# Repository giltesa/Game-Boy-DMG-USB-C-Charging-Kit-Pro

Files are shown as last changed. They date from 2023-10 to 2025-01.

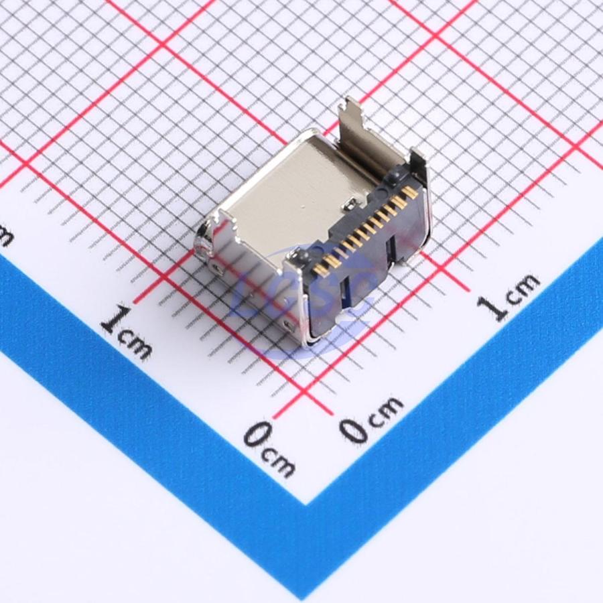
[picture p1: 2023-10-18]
3. Documentation/Datasheet/USB-C/20230608_Hanbo-Electronic-MC-108-DG30_C6332273_back.jpg

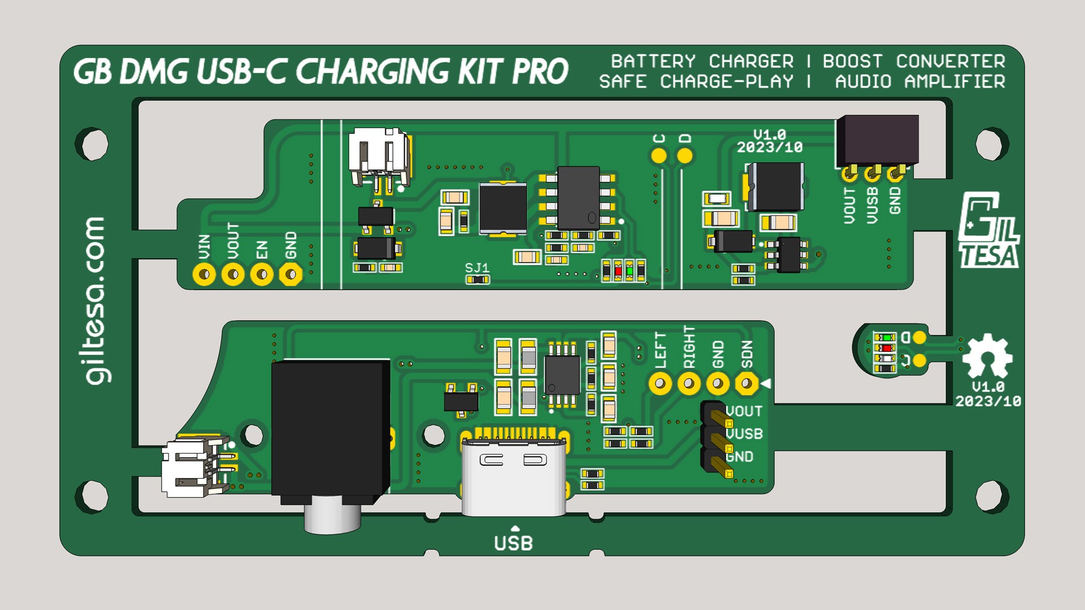
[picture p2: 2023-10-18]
2. Renders, 3D models/GB DMG PRO - v1.0.jpg

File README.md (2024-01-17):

# Game Boy DMG: USB-C Charging Kit PRO

The **Game Boy DMG USB-C Charging Kit PRO** is a new circuit designed specifically for the **Nintendo Game Boy**. This all-in-one circuit includes not only the **charging controller** but also a **boost converter** and **audio amplifier**.

The modern **IPS displays** with backlighting require more power than the original display, and **flash cards** used to load tons of games can quickly drain the battery. To truly enjoy the games, it is recommended to use a rechargeable battery instead of AA batteries.

However, simply using a rechargeable battery is not sufficient. The increased power consumption puts a strain on the original electronics, potentially causing noise in the speaker or headphones.

The typical solution is to add a charging circuit for the battery and a power converter to replace the old, inefficient one included in the GB. Some individuals also add an audio amplifier to enhance the sound quality of the speaker. All these modifications make the GBP function optimally. However, installing them requires numerous cables and may be challenging for individuals without sufficient knowledge.

This board adds all these features with a clean and straightforward installation:

(https://shop.giltesa.com/wp-content/uploads/2023/08/GB-DMG-PRO-v1.2_panel.jpg)

## Would you like it?

https://shop.giltesa.com/product/game-boy-dmg-usb-c-charging-kit/

## More

- [giltesa.com](https://giltesa.com "giltesa.com")
- [twitter.com](https://twitter.com/giltesa "twitter.com")

## License

This project is licensed under a **Creative Commons** license:
**[Attribution-NonCommercial-ShareAlike 4.0 International (CC BY-NC-SA 4.0) ](https://creativecommons.org/licenses/by-nc-sa/4.0/)**

Check the [LICENSE.md](LICENSE.md) for more information.

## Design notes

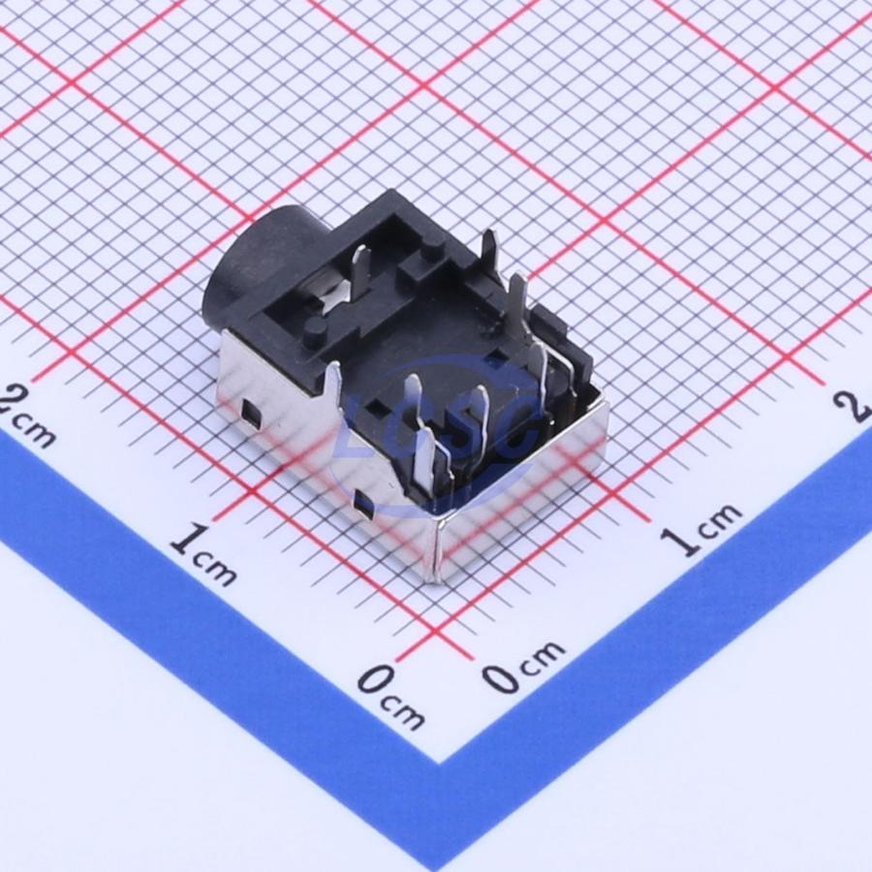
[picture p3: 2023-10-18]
3. Documentation/Datasheet/Headphone jack/20230105_XKB-Connectivity-PJ-3043-B_C2682182_back.jpg

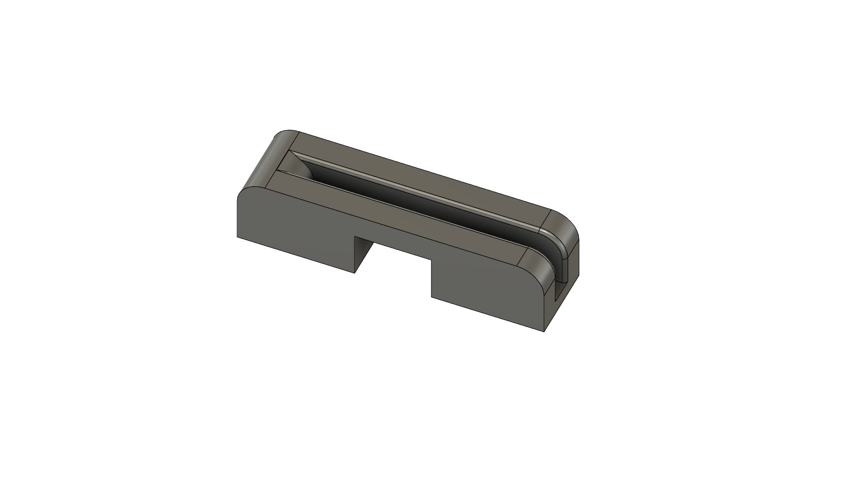
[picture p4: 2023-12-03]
2. Renders, 3D models/Cutting Tool/GB DMG - Cutting Tool v13.png

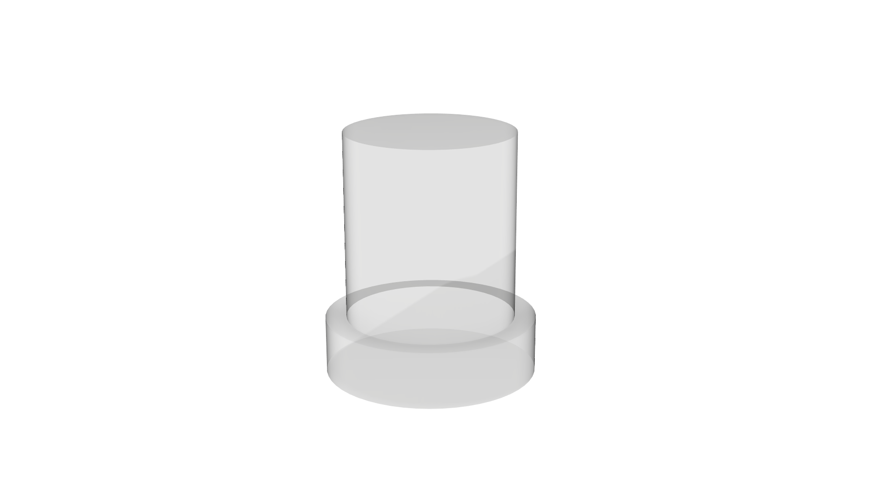
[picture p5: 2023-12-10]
2. Renders, 3D models/Light diffuser pipe/GB DMG - Light diffuser pipe v5.png

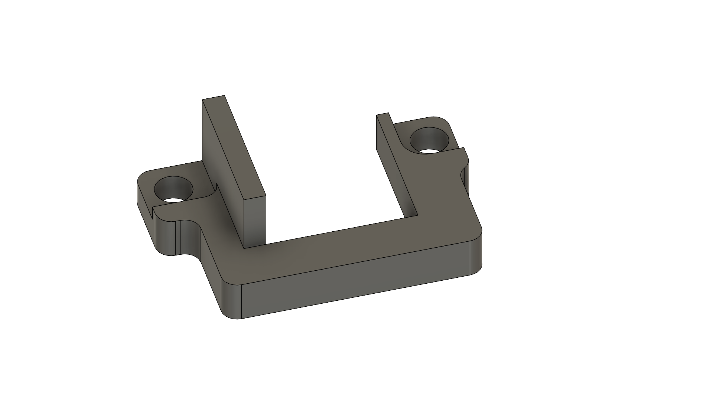
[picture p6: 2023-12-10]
2. Renders, 3D models/Jack Spacer/GB DMG - Jack Spacer v15.png

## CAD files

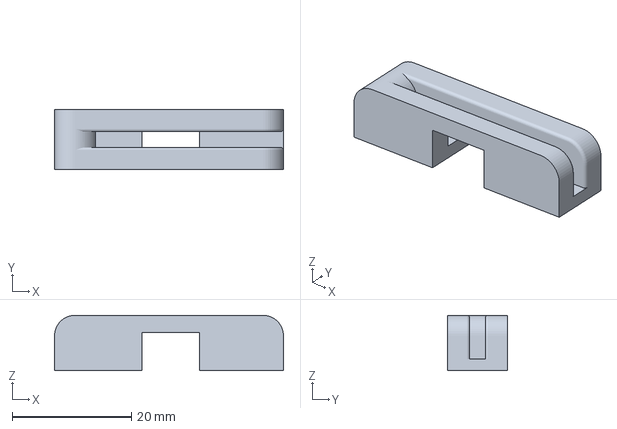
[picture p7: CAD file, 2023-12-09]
2. Renders, 3D models/Cutting Tool/GB DMG - Cutting Tool v13.3mf
38.4 x 10.0 x 9.30 mm

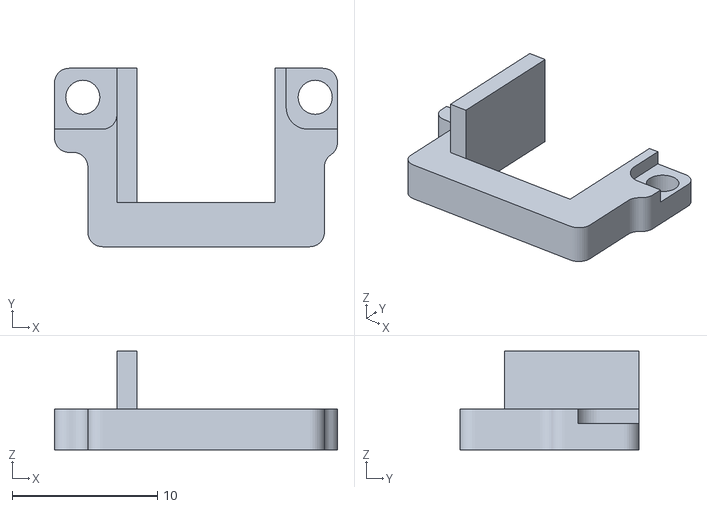
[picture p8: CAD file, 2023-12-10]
2. Renders, 3D models/Jack Spacer/GB DMG - Jack Spacer v15.stl
19.5 x 12.3 x 6.80

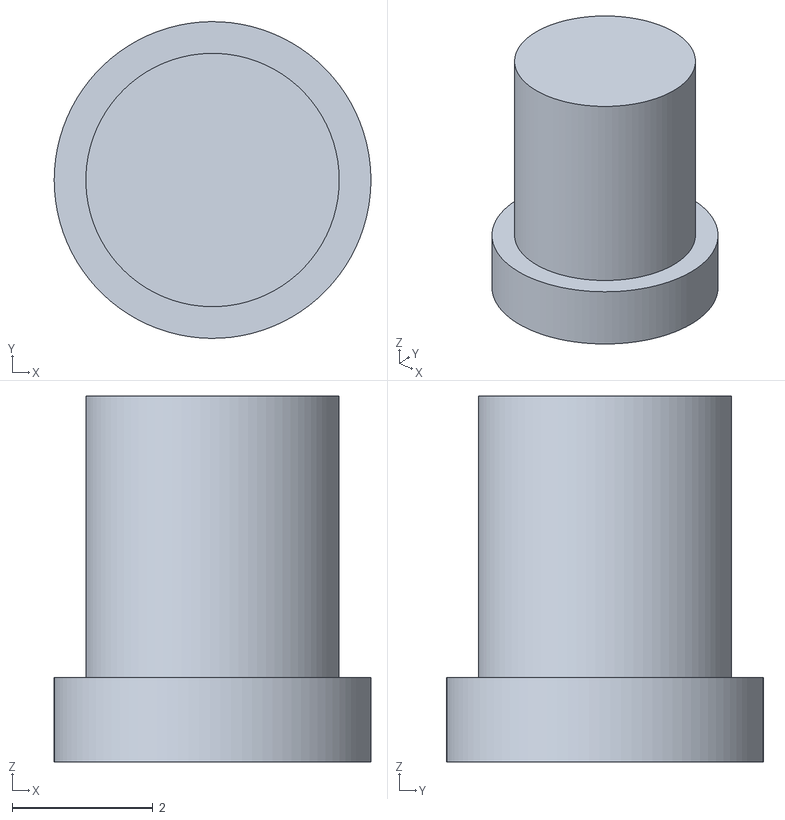
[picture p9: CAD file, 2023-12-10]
2. Renders, 3D models/Light diffuser pipe/GB DMG - Light diffuser pipe v5.stl
4.50 x 4.50 x 5.20

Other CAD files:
2. Renders, 3D models/Cutting Tool/GB DMG - Cutting Tool v13.f3d
2. Renders, 3D models/Cutting Tool/GB DMG - Cutting Tool v13.stl
2. Renders, 3D models/GB DMG - v1.0 - Frame.skp
2. Renders, 3D models/GB DMG - v1.1 - Frame.skp
2. Renders, 3D models/GB DMG - v1.2 - Frame.skp
2. Renders, 3D models/Jack Spacer/GB DMG - Jack Spacer v15.f3d
2. Renders, 3D models/Light diffuser pipe/GB DMG - Light diffuser pipe v5.f3d

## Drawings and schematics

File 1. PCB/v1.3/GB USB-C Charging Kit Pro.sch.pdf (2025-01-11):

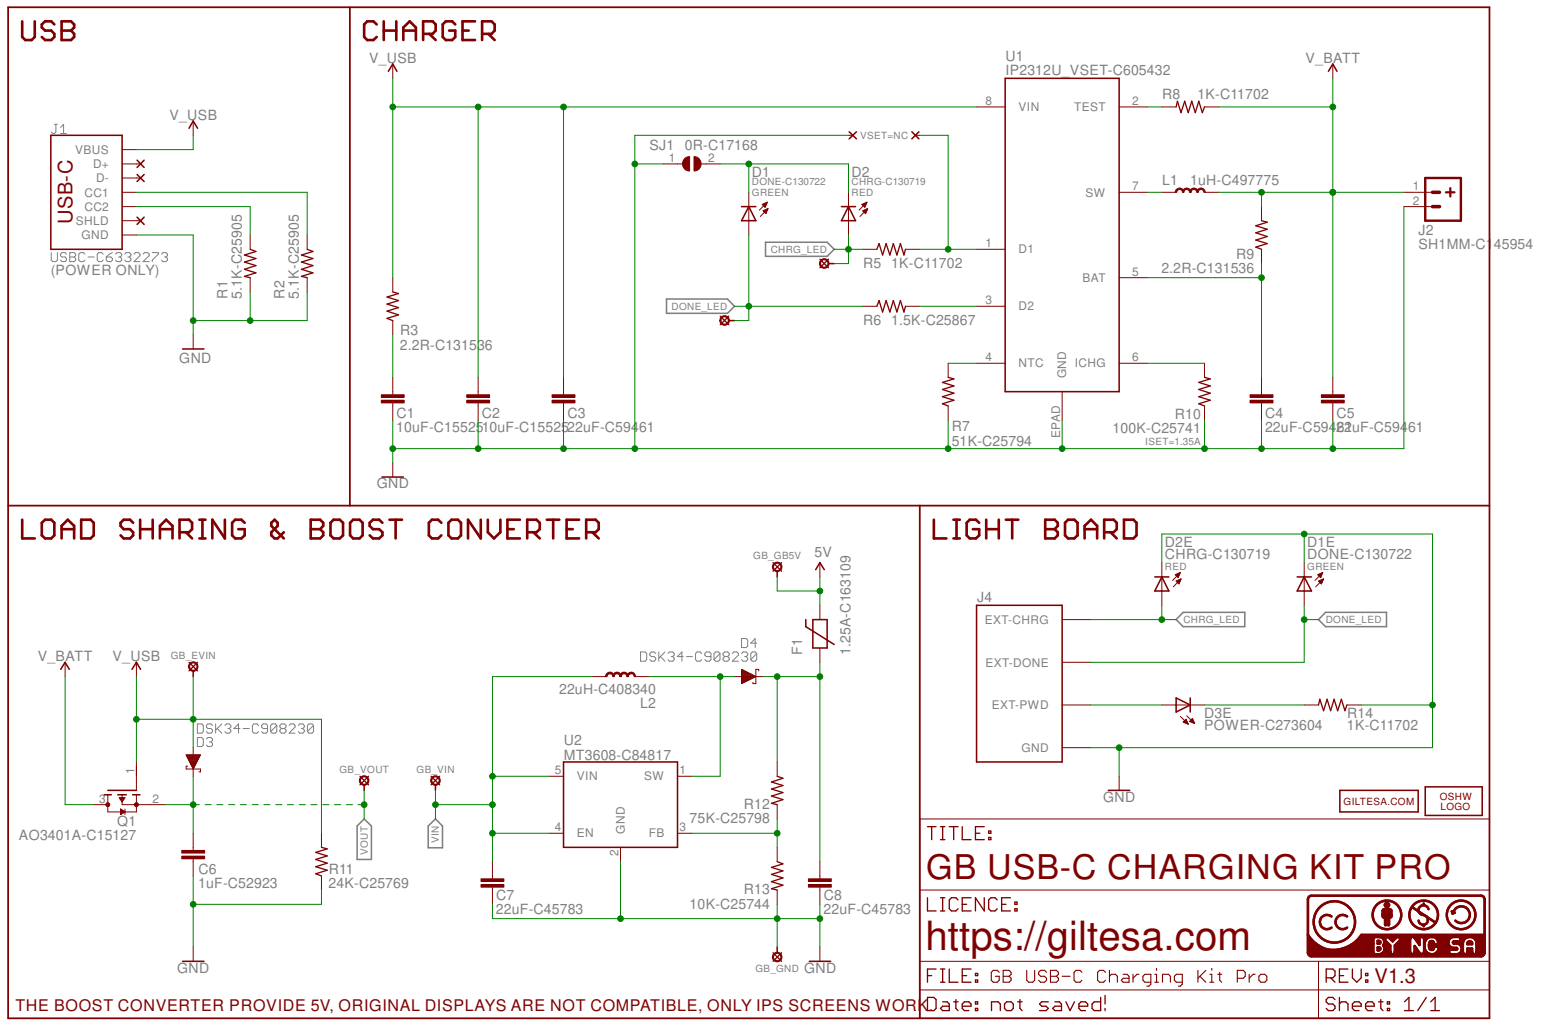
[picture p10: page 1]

D1 1 D2 3 NTC 4 | 1uH-C497775

GB USB-C CHARGING KIT PRO
https://giltesa.com

THE BOOST CONVERTER PROVIDE 5V, ORIGINAL DISPLAYS ARE NOT COMPATIBLE, ONLY IPS SCREENS WORK.

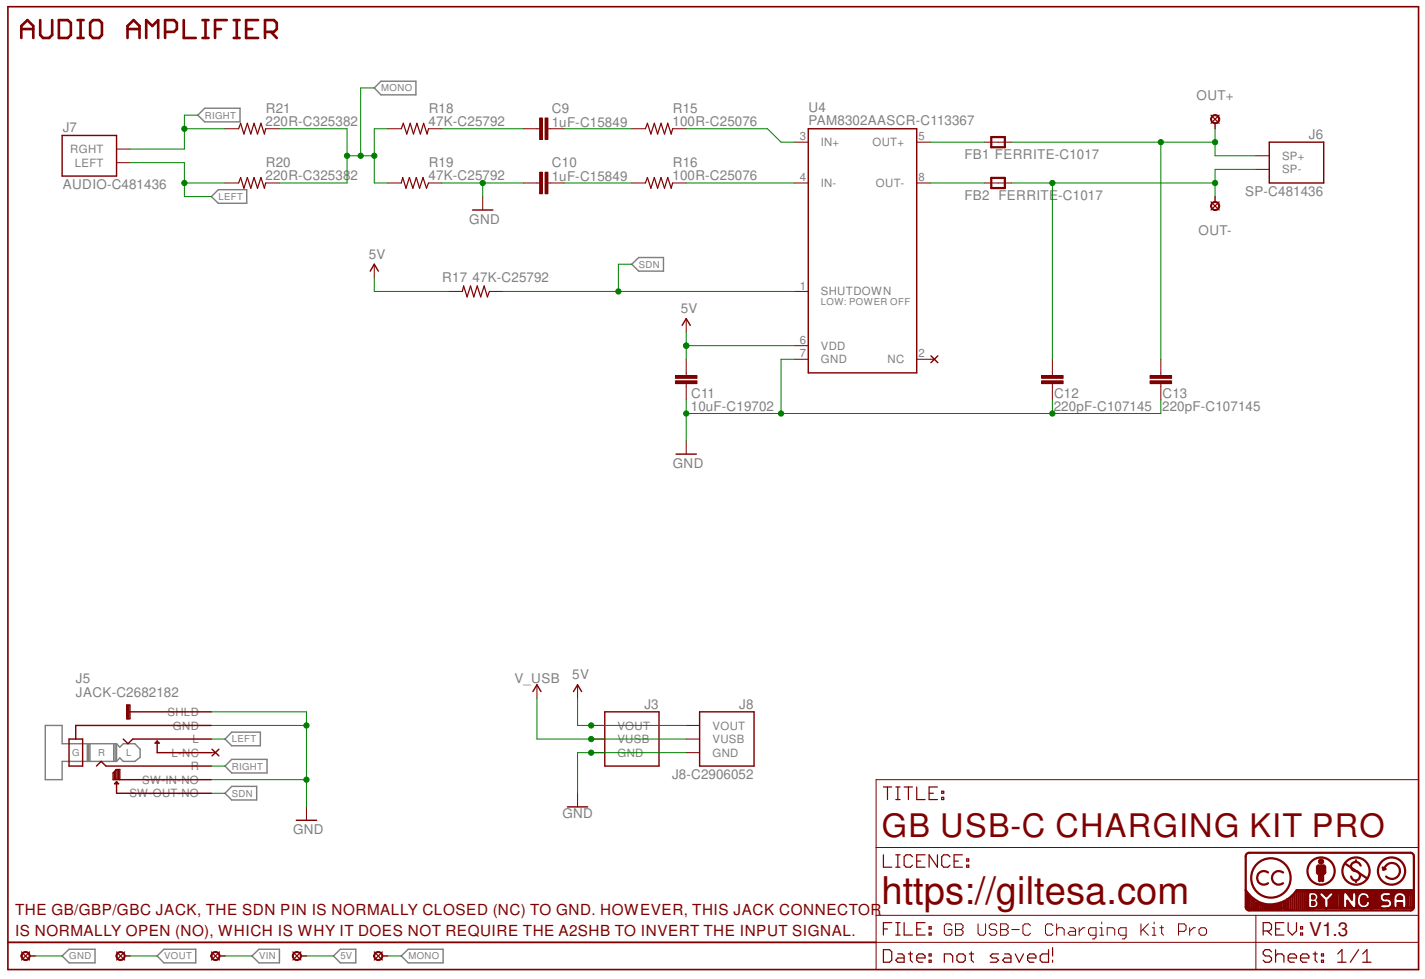
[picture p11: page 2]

GB USB-C CHARGING KIT PRO
https://giltesa.com

THE GB/GBP/GBC JACK, THE SDN PIN IS NORMALLY CLOSED (NC) TO GND. HOWEVER, THIS JACK CONNECTOR
IS NORMALLY OPEN (NO), WHICH IS WHY IT DOES NOT REQUIRE THE A2SHB TO INVERT THE INPUT SIGNAL.

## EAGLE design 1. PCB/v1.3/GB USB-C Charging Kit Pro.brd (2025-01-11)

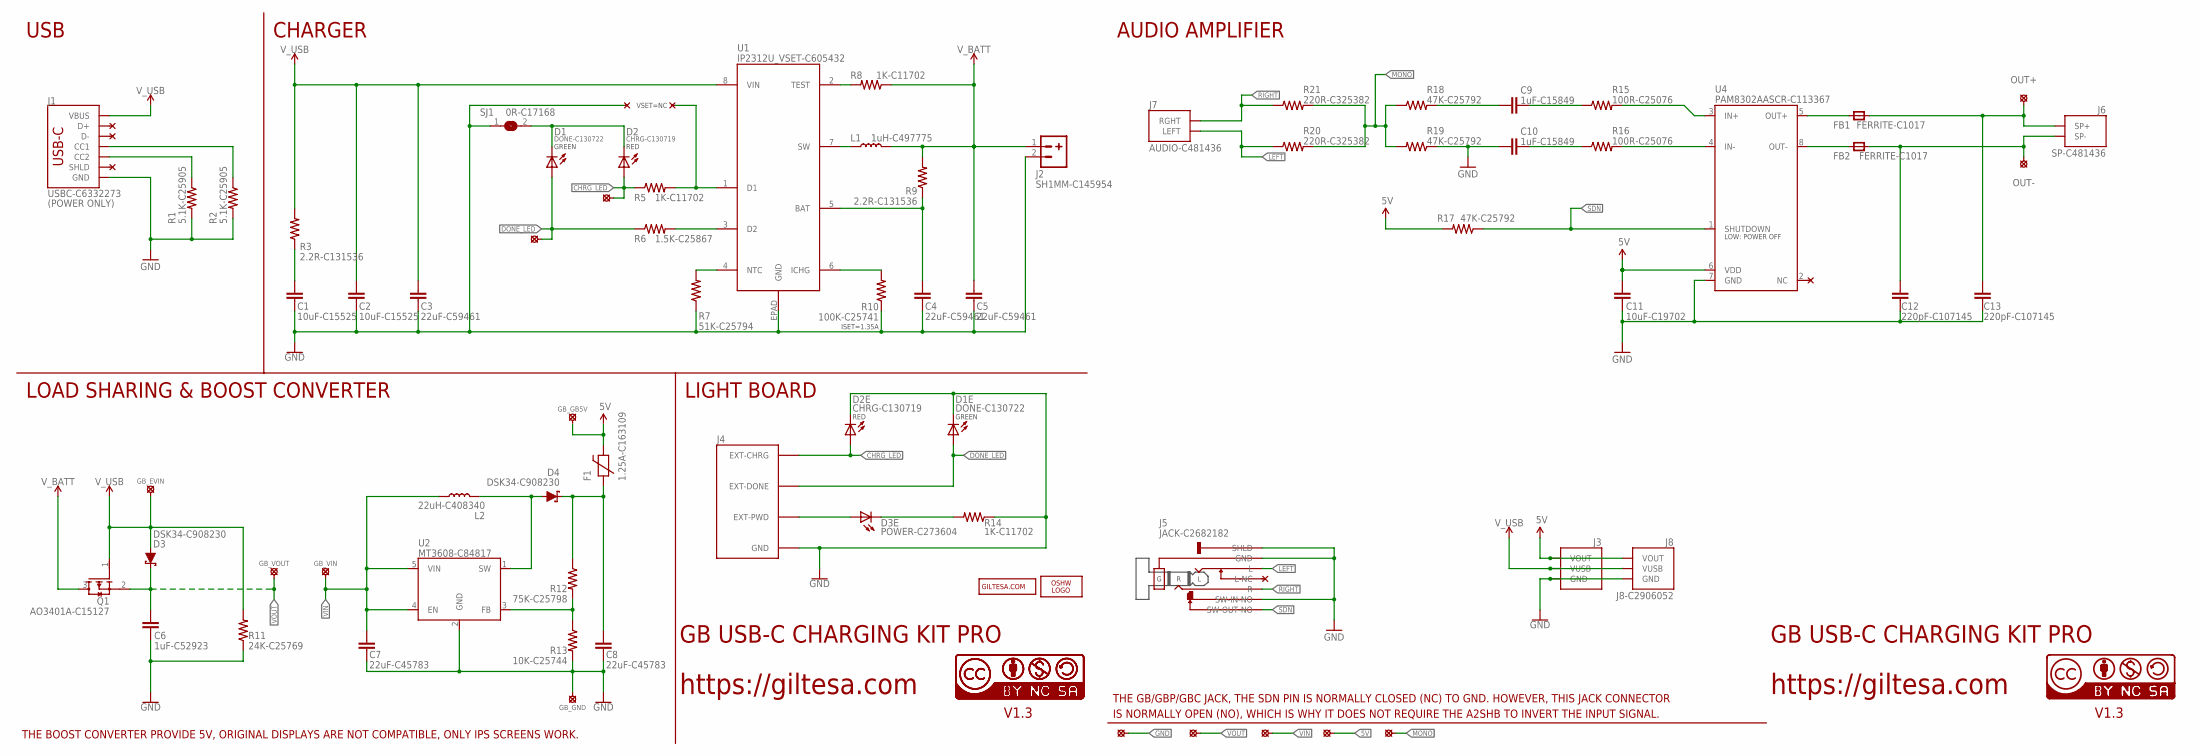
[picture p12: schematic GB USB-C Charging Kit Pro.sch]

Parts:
C1, C2: 10uF-C15525; C0402_S
C3, C4, C5: 22uF-C59461; C0603_S
C6: 1uF-C52923; C0402_S
C7, C8: 22uF-C45783; C0805_S
C9, C10: 1uF-C15849; C0603_S
C11: 10uF-C19702; C0603_S
C12, C13: 220pF-C107145; C0805_S
D1, D1E: DONE-C130722; L0402
D2, D2E: CHRG-C130719; L0402
D3, D4: DSK34-C908230; SOD-123FL
D3E: POWER-C273604; L0402
F1: 1.25A-C163109; F0603_S
FB1, FB2: FERRITE-C1017; MICROBUILDER__0805MP_S
GBL_: LED-C481436; GB_DMG_JST_LED
GB_: POWER-C2845538; GB_DMG_JST_POWER
J1: USBC-C6332273; USB-C_16P_3MM
J2: SH1MM-C145954; JST-2-1MM-SMD_RIGHT
J3: GB_DMG_BRIDGE_2.0MM_UP
J4: GB_DMG_LED
J5: JACK-C2682182; GB_DMG_JACK
J6: SP-C481436; GB_DMG_JST_SPEAKER
J7: AUDIO-C481436; GB_DMG_JST_AUDIO
J8: J8-C2906052; GB_DMG_BRIDGE_2.0MM_RIGHT
L1: 1uH-C497775; PSPMAA0402
L2: 22uH-C408340; PSPMAA0402
LOGO2: OSHW_LOGO_FILLX0150-NT; OSHW_FILLX150_NOTEXT
PP1, PP2, PP3, PP4, PP6: SOLDER_PAD-1.3; SOLDER_PAD_1.3
Q1: AO3401A-C15127; SOT23-3_S
R1, R2: 5.1K-C25905; R0402
R3, R9: 2.2R-C131536; R0402
R5, R8, R14: 1K-C11702; R0402
R6: 1.5K-C25867; R0402
R7: 51K-C25794; R0402
R10: 100K-C25741; R0402
R11: 24K-C25769; R0402
R12: 75K-C25798; R0402
R13: 10K-C25744; R0402
R15, R16: 100R-C25076; R0402
R17, R18, R19: 47K-C25792; R0402
R20, R21: 220R-C325382; R0402
SJ1: 0R-C17168; JUMPER-SMD_0402
U1: IP2312U_VSET-C605432; IP2312
U2: MT3608-C84817; SOT-23-6
U4: PAM8302AASCR-C113367; PAM8302AASCR
U$6: CC-BY-NC-SA15MM; CC-BY-NC-SA_15MM
U$16: GILTESA.COM_MASK; GILTESA.COM_MASK_15MM
U$17, U$21: CC-NC-BCNIX; CC-NC-B_NIX
U$20: OUT+; SOLDER_PAD_1.3
U$23: OUT-; SOLDER_PAD_1.3

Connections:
5V: C11.1, F1.2, GB_.GB5V, J3.VOUT, J8.VOUT, PP1.P$1, R17.2, U4.6 (VDD)
CHRG_LED: D2.A, D2E.A, GBL_.CHRG, J4.EXT-CHRG, R5.1
DONE_LED: D1.A, D1E.A, GBL_.DONE, J4.EXT-DONE, R6.1
GND: C1.1, C2.1, C3.1, C4.1, C5.1, C6.2, C7.1, C8.1, C10.2, C11.2, C12.2, C13.2, D1E.C, D2E.C, GB_.GND, J1.GND1 (GND), J1.GND2 (GND), J2.2, J3.GND, J4.PWD-GND (GND), J4.PWD-GND' (GND), J5.1 (GND), J5.1" (GND), J5.5 (SW-IN-NO), J5.8 (SHLD), J5.8' (SHLD), J8.GND, PP2.P$1, R1.2, R2.2, R7.1, R10.1, R11.1, R13.2, R14.1, R19.1, SJ1.1, U1.EPAD (GND), U2.2 (GND), U4.7 (GND)
LEFT: J5.3 (L), J7.LEFT, R20.1
MONO: PP6.P$1, R18.1, R19.2, R20.2, R21.2
unnamed: D1.C, D2.C, SJ1.2
unnamed: C8.2, D4.C, F1.1, R12.1
unnamed: D4.A, L2.P$2 (2), U2.1 (SW)
unnamed: J1.B5-CC2 (CC2), R1.1
unnamed: R8.2, U1.2 (TEST)
unnamed: R12.2, R13.1, U2.3 (FB)
unnamed: R16.2, U4.4 (IN-)
unnamed: D3E.A, J4.EXT-PWD
unnamed: D3E.C, R14.2
unnamed: R15.2, U4.3 (IN+)
unnamed: J1.A5-CC1 (CC1), R2.1
unnamed: C4.2, R9.1, U1.5 (BAT)
unnamed: C1.2, R3.1
unnamed: C10.1, R16.1
unnamed: FB2.1, U4.8 (OUT-)
unnamed: R5.2, U1.1 (D1)
unnamed: FB1.1, U4.5 (OUT+)
unnamed: C9.1, R15.1
unnamed: C9.2, R18.2
unnamed: R7.2, U1.4 (NTC)
unnamed: R10.2, U1.6 (ICHG)
unnamed: R6.2, U1.3 (D2)
unnamed: L1.P$1 (1), U1.7 (SW)
OUT+: C13.1, FB1.2, J6.SP+, U$20.P$1
OUT-: C12.1, FB2.2, J6.SP-, U$23.P$1
RIGHT: J5.2 (R), J7.RGHT, R21.1
SDN: J5.6 (SW-OUT-NO), R17.1, U4.1 (SHUTDOWN)
VIN: C7.2, GB_.VIN, L2.P$1 (1), PP3.P$1, U2.4 (EN), U2.5 (VIN)
VOUT: C6.1, D3.C, GB_.VOUT, PP4.P$1, Q1.2 (S)
V_BATT: C5.2, J2.1, L1.P$2 (2), Q1.3 (D), R8.1, R9.2
V_USB: C2.2, C3.2, D3.A, GB_.EVIN, J1.VBUS1 (VBUS), J1.VBUS2 (VBUS), J3.VUSB, J8.VUSB, Q1.1 (G), R3.2, R11.2, U1.8 (VIN)

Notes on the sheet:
GB USB-C CHARGING KIT PRO
https://giltesa.com
V1.3
(POWER ONLY)
THE BOOST CONVERTER PROVIDE 5V, ORIGINAL DISPLAYS ARE NOT COMPATIBLE, ONLY IPS SCREENS WORK.
USB
CHARGER
LOAD SHARING & BOOST CONVERTER
AUDIO AMPLIFIER
LIGHT BOARD
ISET=1.35A
GREEN
RED
VSET=NC
THE GB/GBP/GBC JACK, THE SDN PIN IS NORMALLY CLOSED (NC) TO GND. HOWEVER, THIS JACK CONNECTOR
IS NORMALLY OPEN (NO), WHICH IS WHY IT DOES NOT REQUIRE THE A2SHB TO INVERT THE INPUT SIGNAL.

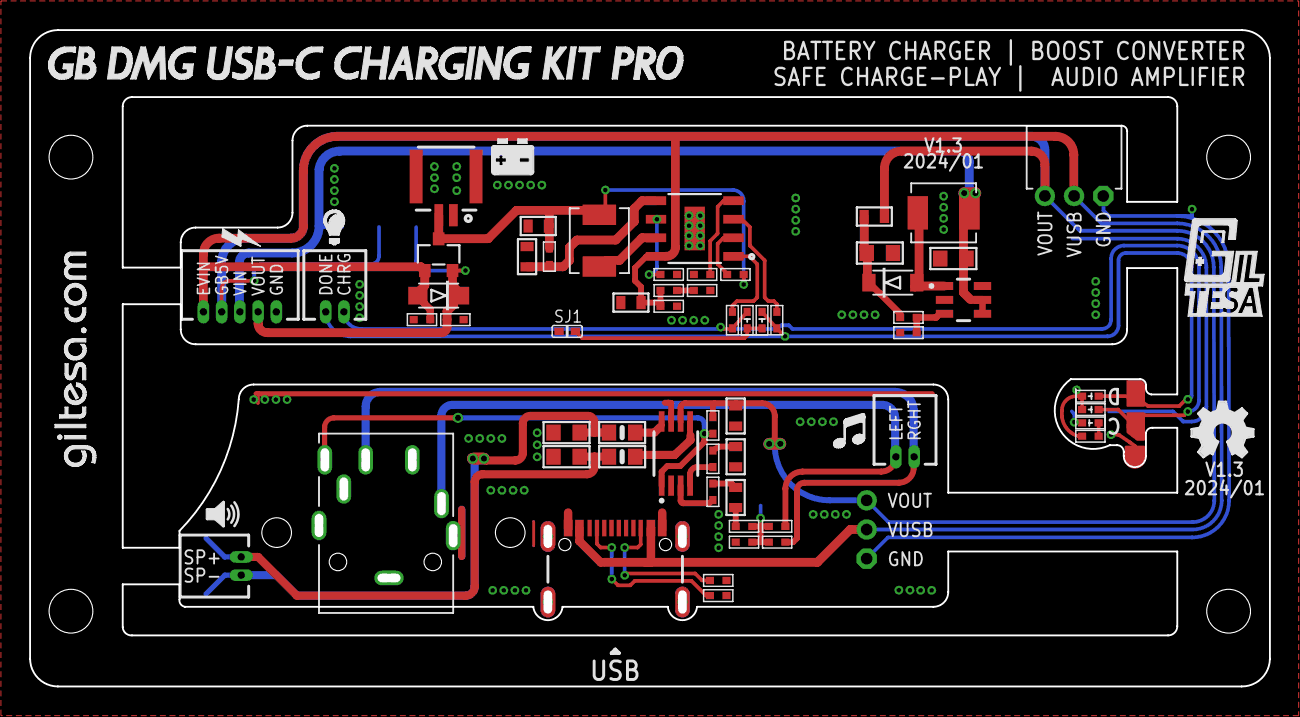
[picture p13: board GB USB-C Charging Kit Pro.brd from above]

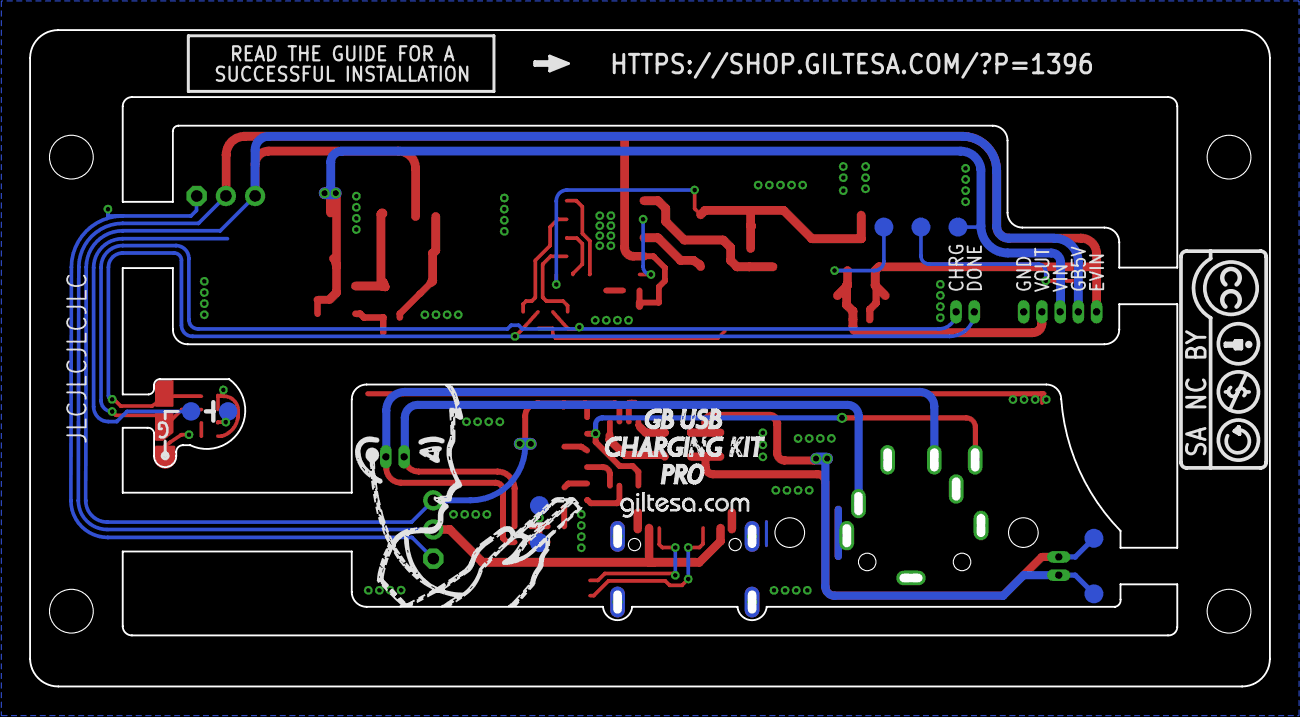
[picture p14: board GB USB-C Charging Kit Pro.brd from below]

Board: 2 copper layers, 85.0 x 45.0 mm, 82 parts (11 on the bottom side), 37 nets.

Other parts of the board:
U$1: SPEAKER
U$4: BATTERY
U$7: GAME_BOY_DMG
U$8: LIGHT
U$9: GILTESA_LOGO_MASK_7MM
U$10: SOUND
U$13: GB_DMG_BOARD_LOGO
U$14: POWER
U$15: GILTESA.COM_MASK_9MM
U$34: GB_DMG_BOARD

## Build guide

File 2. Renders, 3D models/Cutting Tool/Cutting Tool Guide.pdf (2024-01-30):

# Cutting tool for GAME BOY DMG

PRODUCT

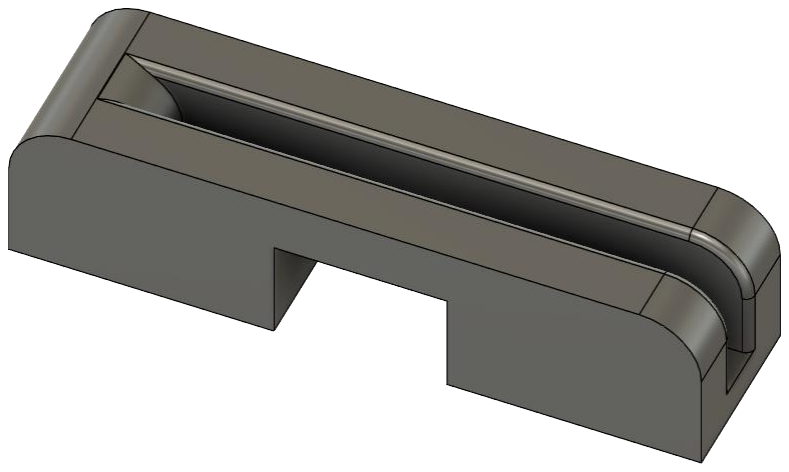
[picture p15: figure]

https://shop.giltesa.com/product/game-boy-dmg-usb-c-cutting-tool

# Description

This plastic tool made by 3D printer will help you to make a perfect hole on your Game Boy DMG shell. It works as a template which helps to drill the hole in the exactly place where it needs to be.

# REQUIRED (NOT INCLUDED)

- Permanent marker (https://www.aliexpress.com/w/wholesale-black-permanent-Marker-0.5mm.html)
- Cutter (https://www.aliexpress.com/wholesale?SearchText=Cutter+scalpel)
- Rotary tool like a Dremel with drill bits or diamond burs for cutting the hole.

# Instructions

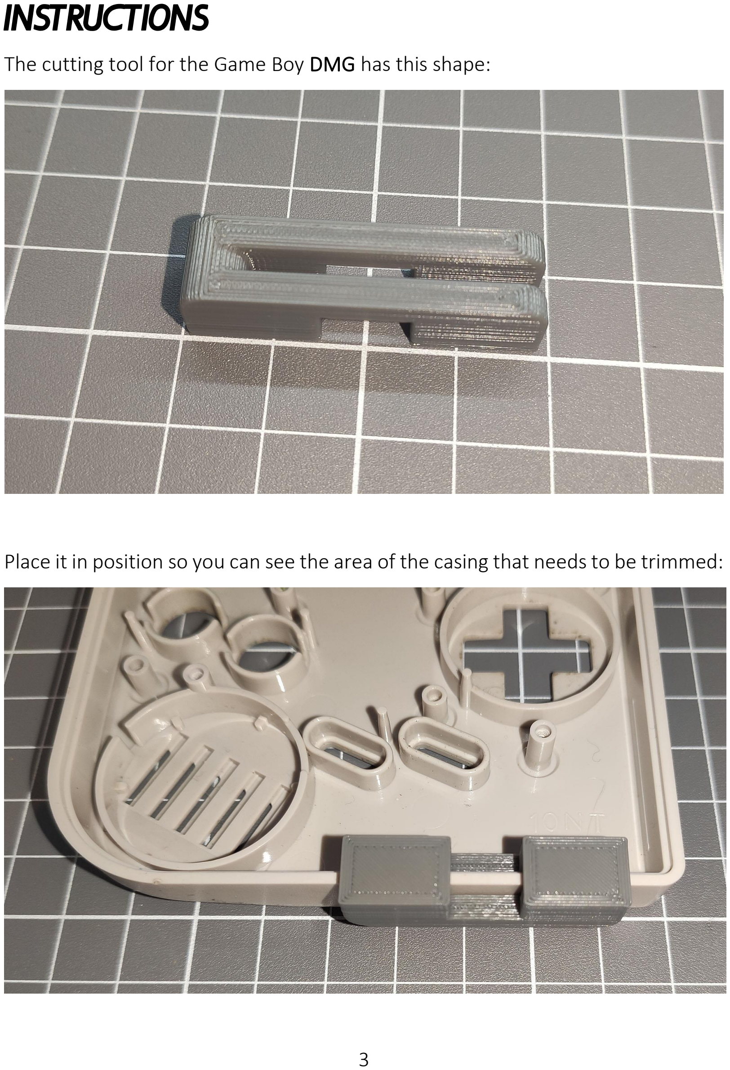
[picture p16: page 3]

The cutting tool for the Game Boy DMG has this shape:

Place it in position so you can see the area of the casing that needs to be trimmed:

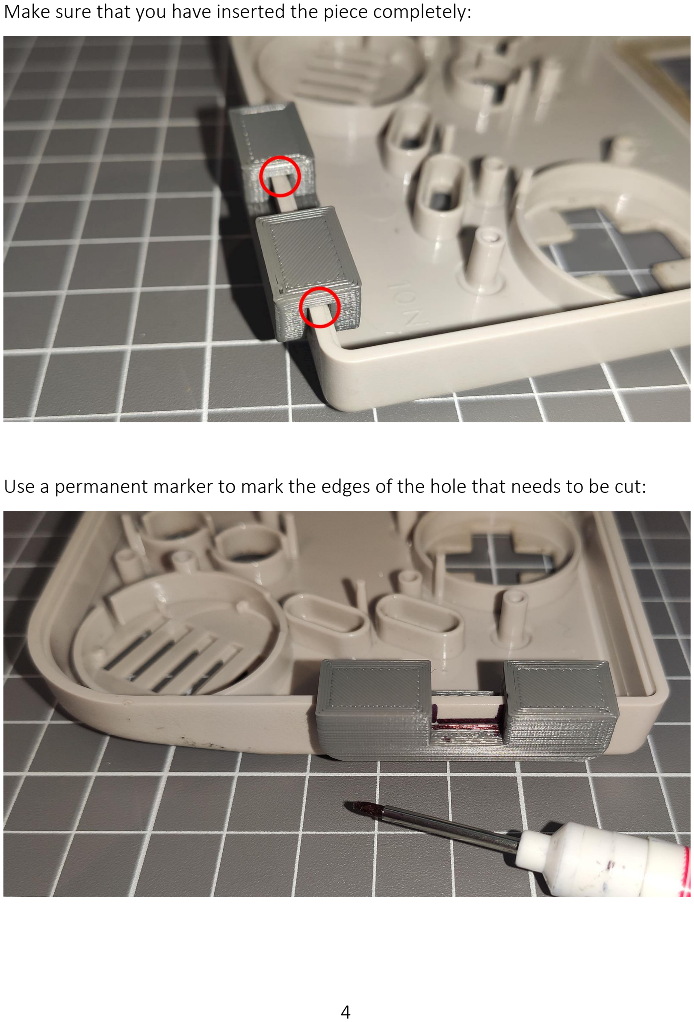
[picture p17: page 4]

Make sure that you have inserted the piece completely:

Use a permanent marker to mark the edges of the hole that needs to be cut:

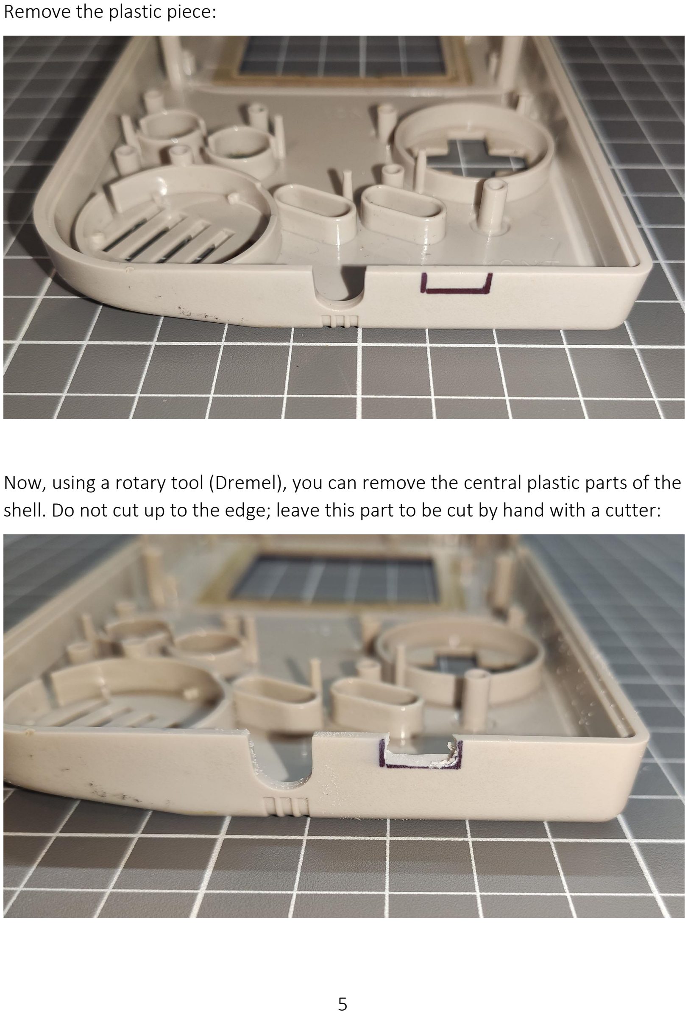
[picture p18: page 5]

Remove the plastic piece:

Now, using a rotary tool (Dremel), you can remove the central plastic parts of the shell. Do not cut up to the edge; leave this part to be cut by hand with a cutter:

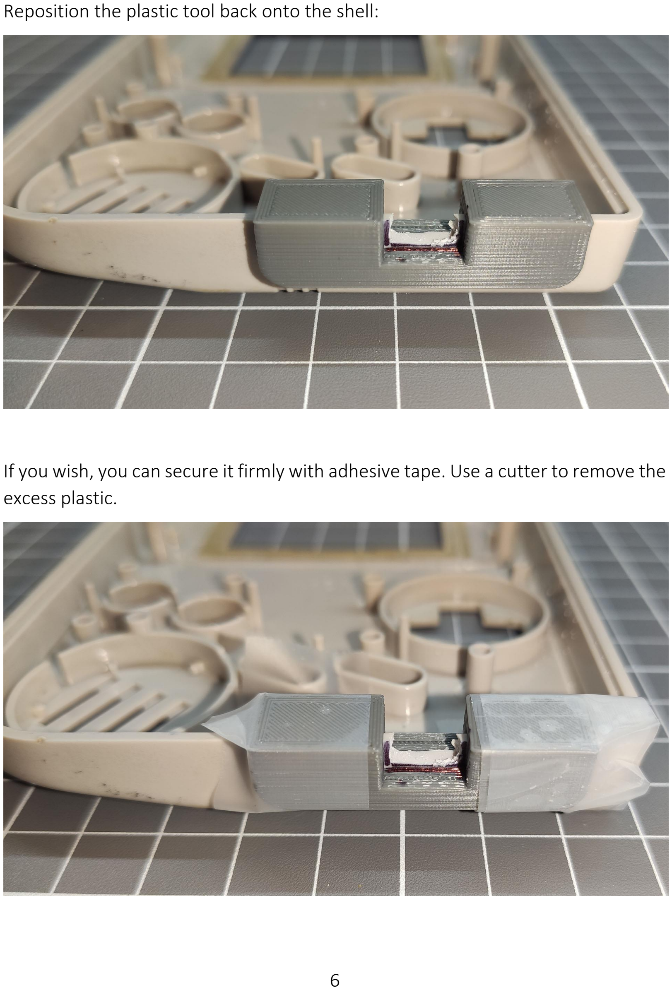
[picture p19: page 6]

Reposition the plastic tool back onto the shell:

If you wish, you can secure it firmly with adhesive tape. Use a cutter to remove the excess plastic.

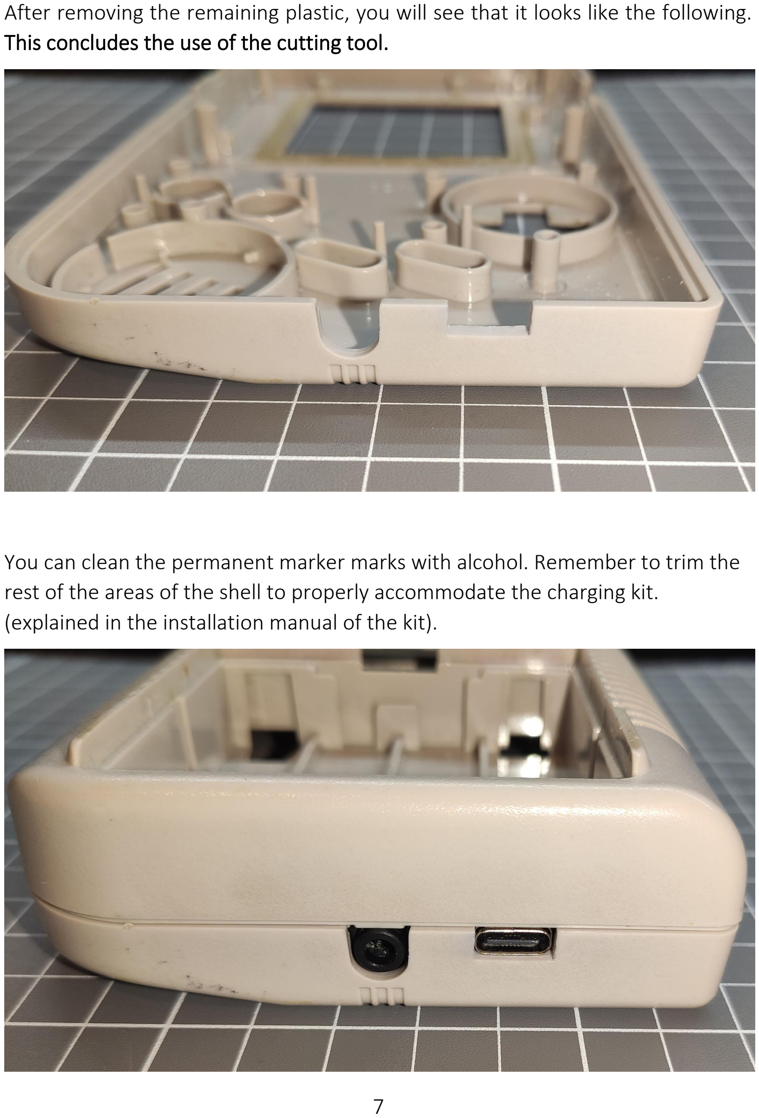
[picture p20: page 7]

After removing the remaining plastic, you will see that it looks like the following. This concludes the use of the cutting tool.

You can clean the permanent marker marks with alcohol. Remember to trim the rest of the areas of the shell to properly accommodate the charging kit. (explained in the installation manual of the kit).

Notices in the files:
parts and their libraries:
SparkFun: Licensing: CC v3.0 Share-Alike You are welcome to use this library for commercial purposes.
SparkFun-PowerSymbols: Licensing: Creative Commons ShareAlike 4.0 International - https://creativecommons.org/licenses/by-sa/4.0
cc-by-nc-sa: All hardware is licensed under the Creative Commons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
